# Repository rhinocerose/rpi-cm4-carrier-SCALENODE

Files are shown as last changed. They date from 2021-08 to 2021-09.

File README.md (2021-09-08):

# Scalenode platform

Copyright (c) 2020-2021 [Antmicro](https://www.antmicro.com>)

[Home Page](https://opensource.antmicro.com/projects/scalenode)



## Overview

This repository contains the PCB design files for a baseboard supporting Raspberry Pi Compute Module 4.
The baseboard has been optimized for 19-inch rack mount installations for distributed multi-node computing systems.

## Key features

* Supports Raspberry Pi CM4
* Gigabit Ethernet with integrated PoE circuitry
* On-board M.2 (key-M) slot supporting NVMe SSDs 
* Slim PCB outline for 1U chassis
* Expansion connector for peripherals connected over USB
* Expansion connector for HDMI adapters

## Board layout and dimensions



## Design status

The PCB design files were prepared in KiCad.
Prototypes of revision 1.0.0 are now being verified.

## License

[Apache-2.0](LICENSE)

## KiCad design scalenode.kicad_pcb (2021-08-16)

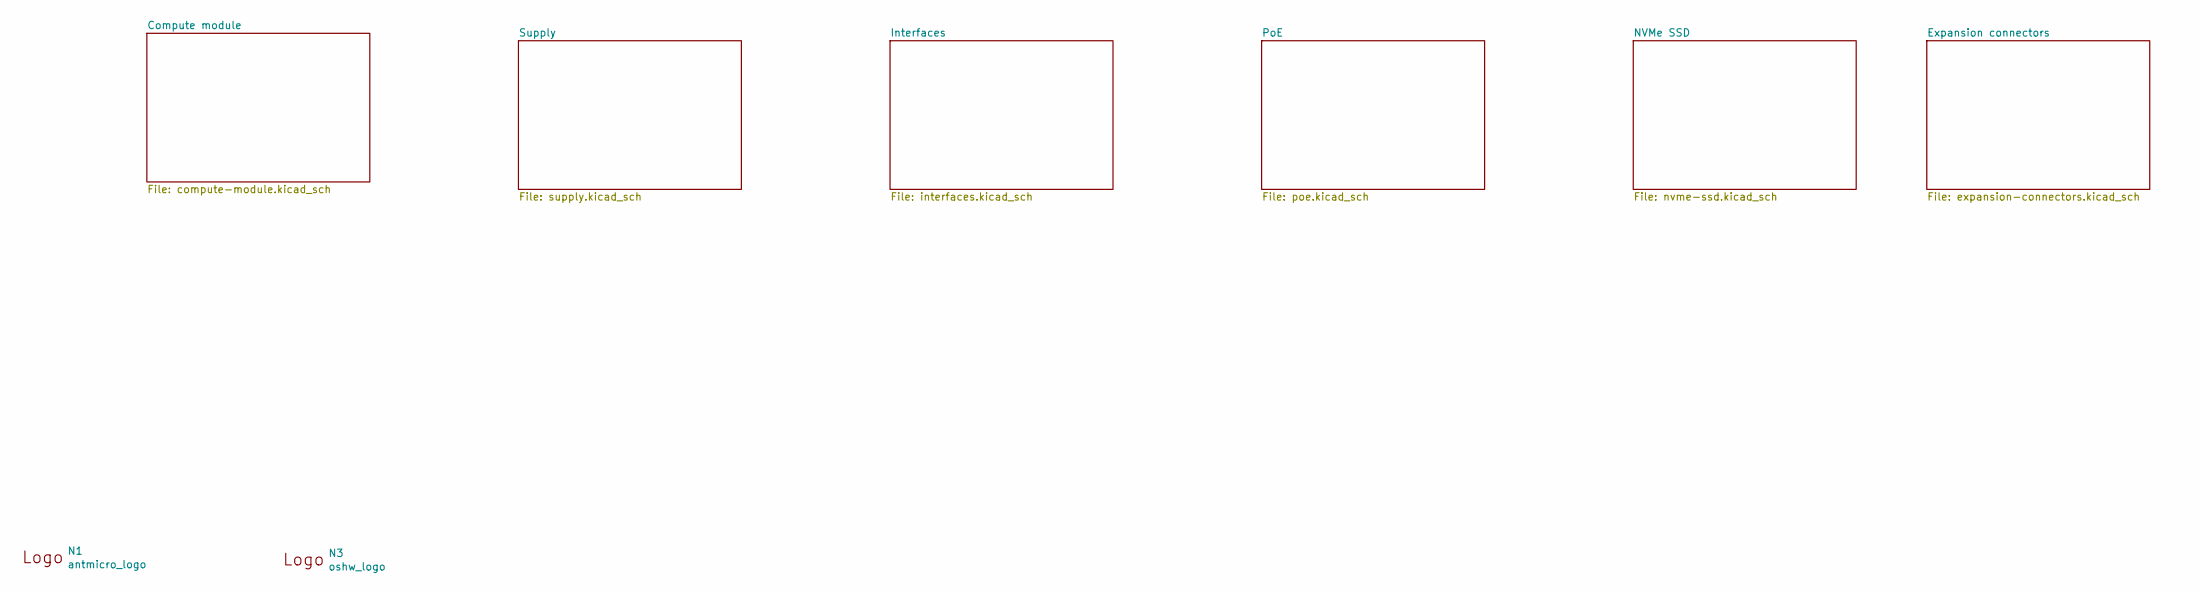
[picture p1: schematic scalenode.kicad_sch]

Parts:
N1: antmicro_logo; antmicro-logo_scaled_15mm
N3: oshw_logo; oshw-logo

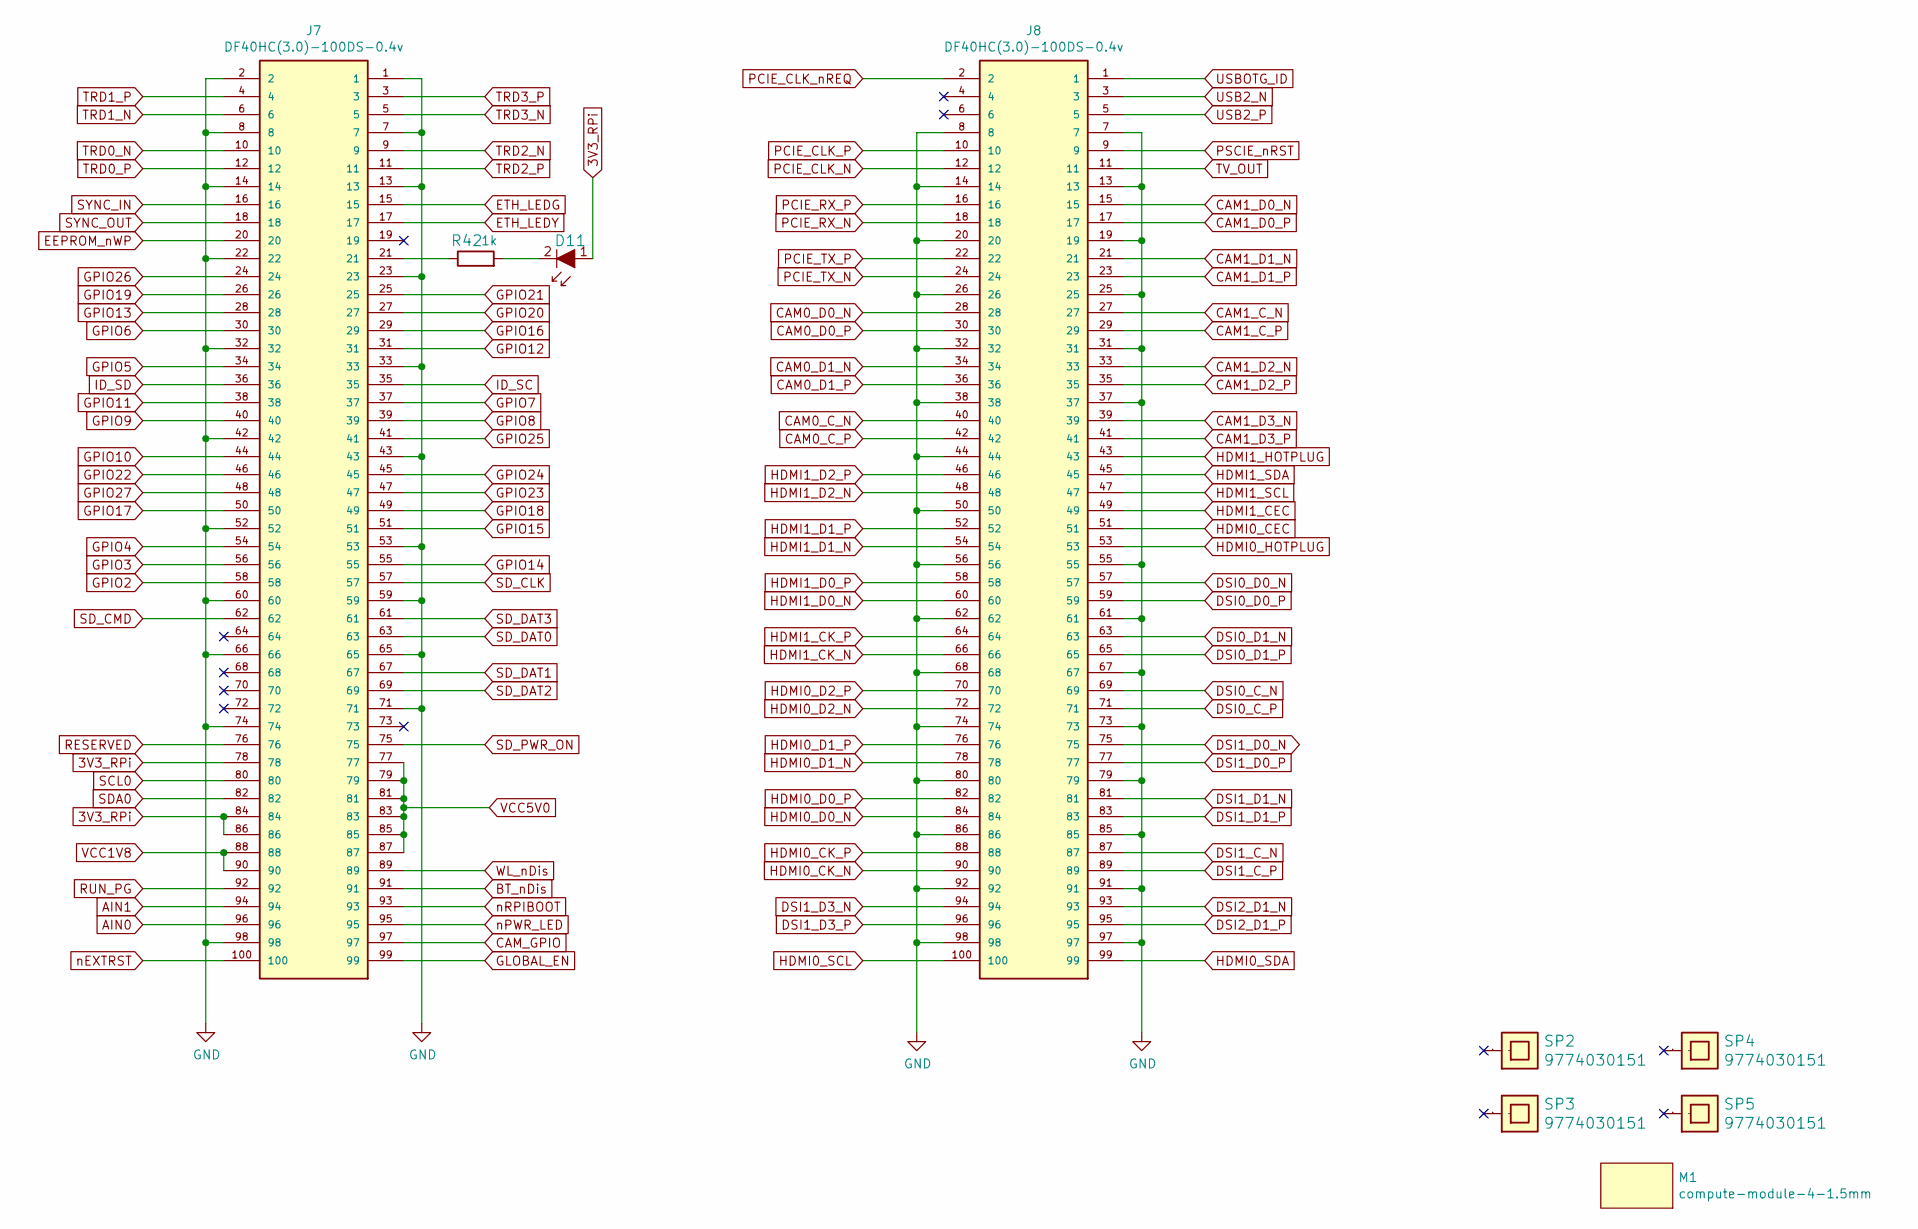
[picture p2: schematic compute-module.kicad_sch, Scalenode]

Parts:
D11: KP-1608CGCK; LED_0603; MPN KP-1608CGCK
J7, J8: DF40HC(3.0)-100DS-0.4v; DF40HC-3.0-100DS-0.4v
M1: compute-module-4-1.5mm
R42: R_1k_0603; 0603-res; MPN CR0603-JW-102ELF
SP2, SP3, SP4, SP5: 9774030151; MPN 9774030151

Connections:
AIN0: J7.96
AIN1: J7.94
BT_nDis: J7.91
CAM0_C_N: J8.40
CAM0_C_P: J8.42
CAM0_D0_N: J8.28
CAM0_D0_P: J8.30
CAM0_D1_N: J8.34
CAM0_D1_P: J8.36
CAM1_C_N: J8.27
CAM1_C_P: J8.29
CAM1_D0_N: J8.15
CAM1_D0_P: J8.17
CAM1_D1_N: J8.21
CAM1_D1_P: J8.23
CAM1_D2_N: J8.33
CAM1_D2_P: J8.35
CAM1_D3_N: J8.39
CAM1_D3_P: J8.41
CAM_GPIO: J7.97
DSI0_C_N: J8.69
DSI0_C_P: J8.71
DSI0_D0_N: J8.57
DSI0_D0_P: J8.59
DSI0_D1_N: J8.63
DSI0_D1_P: J8.65
DSI1_C_N: J8.87
DSI1_C_P: J8.89
DSI1_D0_N: J8.75
DSI1_D0_P: J8.77
DSI1_D1_N: J8.81
DSI1_D1_P: J8.83
DSI1_D3_N: J8.94
DSI1_D3_P: J8.96
DSI2_D1_N: J8.93
DSI2_D1_P: J8.95
EEPROM_nWP: J7.20
ETH_LEDG: J7.15; also elsewhere on the board
ETH_LEDY: J7.17; also elsewhere on the board
GLOBAL_EN: J7.99
GND: J7.1, J7.2, J7.7, J7.8, J7.13, J7.14, J7.22, J7.23, J7.32, J7.33, J7.42, J7.43, J7.52, J7.53, J7.59, J7.60, J7.65, J7.66, J7.71, J7.74, J7.98, J8.7, J8.8, J8.13, J8.14, J8.19, J8.20, J8.25, J8.26, J8.31, J8.32, J8.37, J8.38, J8.44, J8.50, J8.55, J8.56, J8.61, J8.62, J8.67, J8.68, J8.73, J8.74, J8.79, J8.80, J8.85, J8.86, J8.91, J8.92, J8.97, J8.98; also elsewhere on the board
GPIO2: J7.58
GPIO3: J7.56; also elsewhere on the board
GPIO4: J7.54
GPIO5: J7.34
GPIO6: J7.30
GPIO7: J7.37
GPIO8: J7.39
GPIO9: J7.40
GPIO10: J7.44
GPIO11: J7.38
GPIO12: J7.31
GPIO13: J7.28
GPIO14: J7.55
GPIO15: J7.51
GPIO16: J7.29
GPIO17: J7.50
GPIO18: J7.49
GPIO19: J7.26
GPIO20: J7.27
GPIO21: J7.25
GPIO22: J7.46
GPIO23: J7.47
GPIO24: J7.45
GPIO25: J7.41
GPIO26: J7.24
GPIO27: J7.48
HDMI0_CEC: J8.51
HDMI0_CK_N: J8.90
HDMI0_CK_P: J8.88
HDMI0_D0_N: J8.84
HDMI0_D0_P: J8.82
HDMI0_D1_N: J8.78
HDMI0_D1_P: J8.76
HDMI0_D2_N: J8.72
HDMI0_D2_P: J8.70
HDMI0_HOTPLUG: J8.53
HDMI0_SCL: J8.100
HDMI0_SDA: J8.99
HDMI1_CEC: J8.49
HDMI1_CK_N: J8.66
HDMI1_CK_P: J8.64
HDMI1_D0_N: J8.60
HDMI1_D0_P: J8.58
HDMI1_D1_N: J8.54
HDMI1_D1_P: J8.52
HDMI1_D2_N: J8.48
HDMI1_D2_P: J8.46
HDMI1_HOTPLUG: J8.43
HDMI1_SCL: J8.47
HDMI1_SDA: J8.45
ID_SC: J7.35
ID_SD: J7.36
unnamed: D11.2, R42.2
unnamed: J7.21, R42.1
PCIE_CLK_N: J8.12; also elsewhere on the board
PCIE_CLK_P: J8.10; also elsewhere on the board
PCIE_CLK_nREQ: J8.2; also elsewhere on the board
PCIE_RX_N: J8.18; also elsewhere on the board
PCIE_RX_P: J8.16; also elsewhere on the board
PCIE_TX_N: J8.24; also elsewhere on the board
PCIE_TX_P: J8.22; also elsewhere on the board
PSCIE_nRST: J8.9; also elsewhere on the board
RESERVED: J7.76
RUN_PG: J7.92
SCL0: J7.80
SDA0: J7.82
SD_CLK: J7.57; also elsewhere on the board
SD_CMD: J7.62; also elsewhere on the board
SD_DAT0: J7.63; also elsewhere on the board
SD_DAT1: J7.67; also elsewhere on the board
SD_DAT2: J7.69; also elsewhere on the board
SD_DAT3: J7.61; also elsewhere on the board
SD_PWR_ON: J7.75
SYNC_IN: J7.16
SYNC_OUT: J7.18
TRD0_N: J7.10; also elsewhere on the board
TRD0_P: J7.12; also elsewhere on the board
TRD1_N: J7.6; also elsewhere on the board
TRD1_P: J7.4; also elsewhere on the board
TRD2_N: J7.9; also elsewhere on the board
TRD2_P: J7.11; also elsewhere on the board
TRD3_N: J7.5; also elsewhere on the board
TRD3_P: J7.3; also elsewhere on the board
TV_OUT: J8.11
USB2_N: J8.3; also elsewhere on the board
USB2_P: J8.5; also elsewhere on the board
USBOTG_ID: J8.1; also elsewhere on the board
VCC1V8: J7.88, J7.90
VCC5V0: J7.77, J7.79, J7.81, J7.83, J7.85, J7.87; also elsewhere on the board
WL_nDis: J7.89
nEXTRST: J7.100
nPWR_LED: J7.95
nRPIBOOT: J7.93

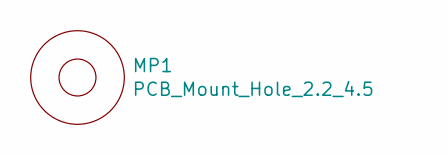
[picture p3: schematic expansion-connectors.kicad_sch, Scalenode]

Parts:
MP1: PCB_Mount_Hole_2.2_4.5; mounting-hole-2.2mm

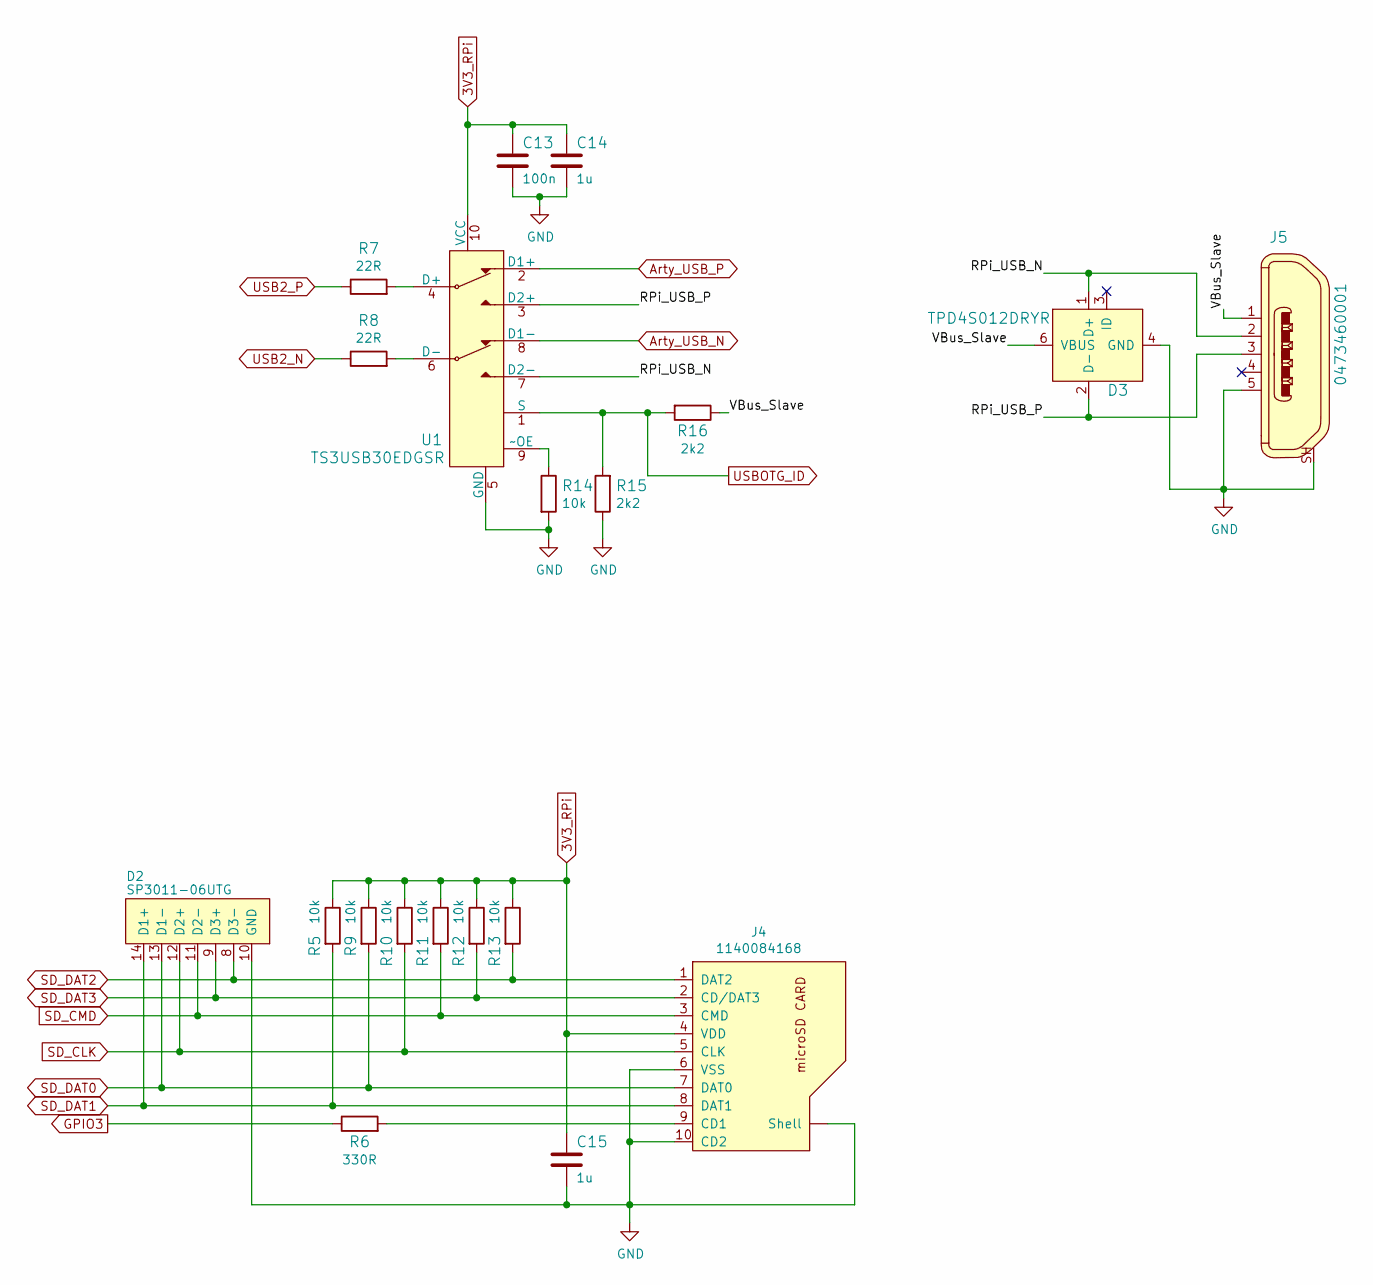
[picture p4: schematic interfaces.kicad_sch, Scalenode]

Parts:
C13: C_100n_0402; 0402-cap; MPN 0402X104K6R3CT
C14, C15: C_1u_0402; 0402-cap; MPN C1005X6S1A105K050BC
D2: SP3011-06UTG; SON50P350X135X55-14N; MPN SP3011-06UTG
D3: TPD4S012DRYR; UFDFN-6_1.45x1mm; MPN TPD4S012DRYR
J4: 1140084168; MicroSD_1140084168; MPN 1140084168
J5: 0473460001; USB_Micro_B_Female_0473460001; MPN 0473460001
R5, R9, R10, R11, R12, R13, R14: R_10k_0402; 0402-res; MPN CRCW040210K0FKEDHP
R6: R_330R_0402; 0402-res; MPN MCMR04X3300FTL
R7, R8: R_22R_0402; 0402-res; MPN CRCW040222R0FKED
R15, R16: R_2k2_0402; 0402-res; MPN RC0402FR-072K2L
U1: TS3USB30EDGSR; MSOP-10_W3mm; MPN TS3USB30EDGSR

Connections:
/Interfaces/RPi_USB_N: D3.1 (D+), J5.2, U1.7 (D2-)
/Interfaces/RPi_USB_P: D3.2 (D-), J5.3, U1.3 (D2+)
Arty_USB_N: U1.8 (D1-)
Arty_USB_P: U1.2 (D1+)
GND: C13.2, C14.2, C15.2, D2.10 (GND), D3.4 (GND), J4.6 (VSS), J4.10 (CD2), J4.~ (Shell), J5.5, J5.SH, R14.2, R15.1, U1.5 (GND); also elsewhere on the board
GPIO3: R6.1; also elsewhere on the board
unnamed: J4.9 (CD1), R6.2
unnamed: R7.2, U1.4 (D+)
unnamed: R8.2, U1.6 (D-)
unnamed: R14.1, U1.9 (~OE)
SD_CLK: D2.12 (D2+), J4.5 (CLK), R10.2; also elsewhere on the board
SD_CMD: D2.11 (D2-), J4.3 (CMD), R11.2; also elsewhere on the board
SD_DAT0: D2.13 (D1-), J4.7 (DAT0), R9.2; also elsewhere on the board
SD_DAT1: D2.14 (D1+), J4.8 (DAT1), R5.2; also elsewhere on the board
SD_DAT2: D2.8 (D3-), J4.1 (DAT2), R13.2; also elsewhere on the board
SD_DAT3: D2.9 (D3+), J4.2 (CD/DAT3), R12.2; also elsewhere on the board
USB2_N: R8.1; also elsewhere on the board
USB2_P: R7.1; also elsewhere on the board
USBOTG_ID: R15.2, R16.2, U1.1 (S); also elsewhere on the board

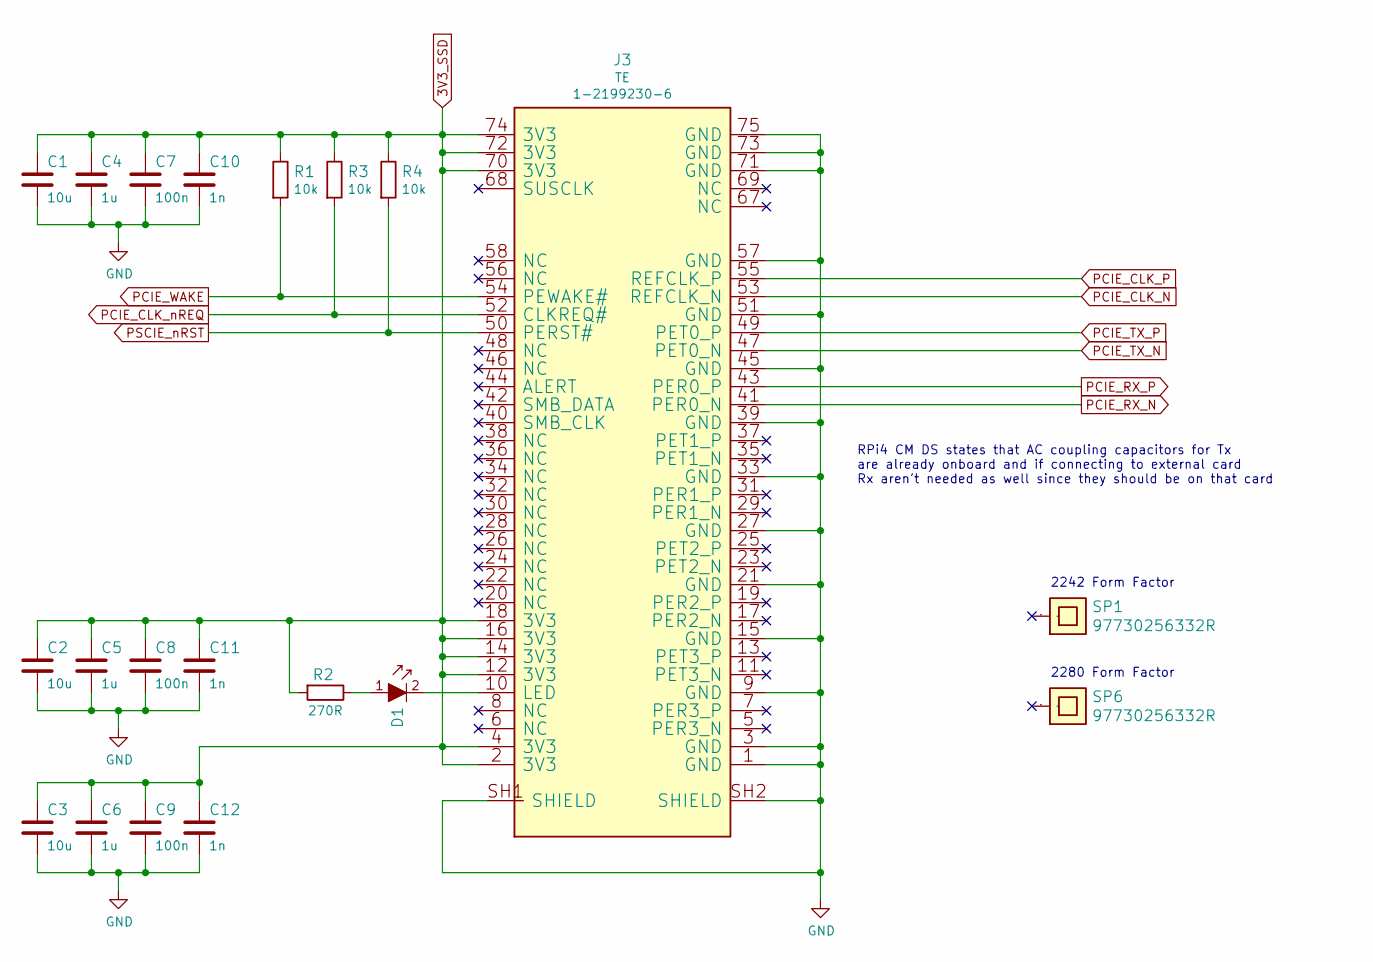
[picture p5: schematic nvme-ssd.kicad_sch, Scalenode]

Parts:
C1, C2, C3: C_10u_0603; 0603-cap; MPN GRM188R61A106KE69D
C4, C5, C6: C_1u_0603; 0603-cap; MPN 0603YD105KAT2A
C7, C8, C9: C_100n_0603; 0603-cap; MPN 0603YC104KAZ2A
C10, C11, C12: C_1n_0603; 0603-cap; MPN 06031C102JAT2A
D1: KP-1608CGCK; LED_0603; MPN KP-1608CGCK
J3: 1-2199230-6; MPN 1-2199230-6
R1, R3, R4: R_10k_0603; 0603-res; MPN CR0603-JW-103ELF
R2: R_270R_0603; 0603-res; MPN CRGH0603F270R
SP1, SP6: 97730256332R; MPN 97730256332R

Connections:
3V3_SSD: C1.1, C2.1, C3.1, C4.1, C5.1, C6.1, C7.1, C8.1, C9.1, C10.1, C11.1, C12.1, J3.2 (3V3), J3.4 (3V3), J3.12 (3V3), J3.14 (3V3), J3.16 (3V3), J3.18 (3V3), J3.70 (3V3), J3.72 (3V3), J3.74 (3V3), R1.1, R2.2, R3.1, R4.1; also elsewhere on the board
GND: C1.2, C2.2, C3.2, C4.2, C5.2, C6.2, C7.2, C8.2, C9.2, C10.2, C11.2, C12.2, J3.1 (GND), J3.3 (GND), J3.9 (GND), J3.15 (GND), J3.21 (GND), J3.27 (GND), J3.33 (GND), J3.39 (GND), J3.45 (GND), J3.51 (GND), J3.57 (GND), J3.71 (GND), J3.73 (GND), J3.75 (GND), J3.SH1 (SHIELD), J3.SH2 (SHIELD); also elsewhere on the board
unnamed: D1.1, R2.1
unnamed: D1.2, J3.10 (LED)
PCIE_CLK_N: J3.53 (REFCLK_N); also elsewhere on the board
PCIE_CLK_P: J3.55 (REFCLK_P); also elsewhere on the board
PCIE_CLK_nREQ: J3.52 (CLKREQ#), R3.2; also elsewhere on the board
PCIE_RX_N: J3.41 (PER0_N); also elsewhere on the board
PCIE_RX_P: J3.43 (PER0_P); also elsewhere on the board
PCIE_TX_N: J3.47 (PET0_N); also elsewhere on the board
PCIE_TX_P: J3.49 (PET0_P); also elsewhere on the board
PCIE_WAKE: J3.54 (PEWAKE#), R1.2
PSCIE_nRST: J3.50 (PERST#), R4.2; also elsewhere on the board

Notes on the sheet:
RPi4 CM DS states that AC coupling capacitors for Tx are already onboard and if connecting to external card Rx aren't needed as well since they should be on that card
2242 Form Factor
2280 Form Factor

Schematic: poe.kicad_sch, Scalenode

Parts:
C20, C21, C23, C24: C_10n_0402; 0402-cap; MPN 04025G103ZAT2A
C22, C25, C50: C_1n_1210_2kV; 1210-cap; MPN C1210C102KGRACTU
C26: C_10n_0603; 0603-cap; MPN 06031C103JAT2A
C27: C_270p_0603; 0603-cap; MPN MC0603B271K500CT
C28: C_100n_0805_100V; 0805-cap; MPN CL21B104KCFNNNE
C29: C_47u_ELEC_100V; CP_Elec_10x10.5; MPN EEEHA2A470UP
C30: C_100n_0603; 0603-cap; MPN 0603YC104KAZ2A
C31: C_220n_0603_25V; 0603-cap; MPN C1608X5R1H474K080AB
C32, C34, C36: C_1u_1210_100V; 1210-cap; MPN 12101C105K4Z2A
C33: C_22u_ELEC_25V; CP_Elec_5x5.8; MPN EEEFK1E220R
C35, C43, C47: C_1u_0603; 0603-cap; MPN 0603YD105KAT2A
C37, C40: C_470n_0603; 0603-cap; MPN C1608X5R1H474K080AB
C38: C_100p_0402; 0402-cap; MPN 0402N101J500CT
C39: C_82n_0603; 0603-cap; MPN MC0603B823K500CT
C41, C42, C44: C_47u_0603; 0603-cap; MPN GRM188R60J476ME15D
C45, C46: C_220u_KEMET_B; KEMET_B; MPN TMCMB0J227MTRF
C48: C_1n_0603; 0603-cap; MPN 06031C102JAT2A
C49: C_1n2_0603; 0603-res; MPN C0603C122K5RACTU
D4, D5: MB10S; MPN MB10S
D6: SMAJ58A-13-F; DO-214AC; MPN SMAJ58A-13-F
D7, D9: BAS16E6327HTSA1; SOT-23-3; MPN BAS16E6327HTSA1
D8: KP-1608CGCK; LED_0603; MPN KP-1608CGCK
D10: MURA120T3G; DO-214AC; MPN MURA120T3G
D12: TLV431ACDBVR; SOT-23-5; MPN TLV431ACDBVR
D13, D14: BAV99W,115; SOT-323; MPN BAV99W,115
FB1, FB2: BLM21PG221SN1D; 0805-res; MPN BLM21PG221SN1D
IC2: TPS2378DDA; SOIC127P600X170-9N; MPN TPS2378DDA; Mouser Part Number 595-TPS2378DDA
J6: SS-74800-144; MPN SS-74800-144
L3: H6096NL; SOIC127P1594X685-24N; MPN H6096NL
L4: DO1608C-332MLB; L_6.3x4.5; MPN DO1608C-332MLB
L5: DR74-R33-R; L_DR74; MPN DR74-R33-R
Q1, Q2, Q5: MMBT3906,215; SOT-23-3; MPN MMBT3906,215
Q3: SI7848BDP-T1-E3; PowerPAK_SO-8_Single; MPN SI7848BDP-T1-E3
Q4: SI7450DP-T1-GE3; PowerPAK_SO-8_Single; MPN SI7450DP-T1-GE3
R17: R_0R_1206; 1206-res; MPN MCMR12X000_PTL
R21, R22: R_220R_0402; 0402-res; MPN ERJ2GEJ221X
R23, R24, R25, R26, R27, R28, R29, R30: R_75R_0402; 0402-res; MPN RC0402FR-0775RL
R31: R_10k7_0603; 0603-res; MPN CRCW060310K7FKEA
R32, R35, R47, R49: R_10k_0603; 0603-res; MPN CR0603-JW-103ELF
R33: R_4k64_0603; 0603-res; MPN CRCW06034K64FKEA
R34: R_63R4_0402; 0402-res; MPN CRCW040263R4FKED
R36: R_24k9_0402; 0402-res; MPN WR04X2492FTL
R37: R_30k1_0603; 0603-res; MPN CRCW060330K1FKEA
R38: R_4k99_0402; 0402-res; MPN MCMR04X4991FTL
R39: R_24R9_0603; 0603-res; MPN CRCW060324R9FKEA
R40: R_15k_0603; 0603-res; MPN CR0603-FX-1502ELF
R41: R_20R_0603; 0603-res; MPN CRCW060320R0FKEA
R43: R_R33_2512; 2512; MPN RLP73K3AR33JTE
R44: R_1k_0402; 0402-res; MPN CR0402-FX-1001GLF
R45, R46: R_1k_0603; 0603-res; MPN CR0603-JW-102ELF
R48, R53: R_49R9_0603; 0603-res; MPN CRCW060349R9FKEA
R50: R_10R_2010; 2010-res; MPN WF20P10R0FTL
R51, R54: R_41k2_0603; 0603-res; MPN CRCW060341K2FKEA
R52: R_13k3_0603; 0603-res; MPN CRCW060313K3FKEA
T1: P0926NL; Pulse_P0926NL; MPN P0926
T2: POE300F-50L; POE300F-24LD; MPN POE300F-50L
TP3, TP4, TP5, TP6: TP_SMD1MM; Testpoint_smd_1mm
U3: UCC3809D2; SOIC-8_W3.9mm; MPN UCC3809D2
U4: TCMT1107; MPN TCMT1107

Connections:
/PoE/CDB: C26.1, IC2.6 (CDB), U3.2 (SS)
/PoE/CTRL_FB: C38.1, R35.1, R44.2, R45.1, U3.1 (FB)
/PoE/CTRL_OUT: C37.2, R39.1, U3.6 (OUT)
/PoE/CTRL_REF: C35.1, R38.1, U3.8 (REF), U4.4
/PoE/CTRL_VDD: C31.1, C33.1, D7.3, D8.1, R37.2, TP3.1, U3.7 (VDD)
/PoE/PAIR12: C20.1, D4.3, L3.24 (MCT1)
/PoE/PAIR36: C21.1, D4.4, L3.21 (MCT2)
/PoE/PAIR45: C23.1, D5.3, L3.18 (MCT3)
/PoE/PAIR78: C24.1, D5.4, L3.15 (MCT4)
/PoE/T_ETH_D0_N: J6.2, L3.22 (MX1-)
/PoE/T_ETH_D0_P: J6.1, L3.23 (MX1+)
/PoE/T_ETH_D1_N: J6.6, L3.19 (MX2-)
/PoE/T_ETH_D1_P: J6.3, L3.20 (MX2+)
/PoE/T_ETH_D2_N: J6.5, L3.16 (MX3-)
/PoE/T_ETH_D2_P: J6.4, L3.17 (MX3+)
/PoE/T_ETH_D3_N: J6.8, L3.13 (MX4-)
/PoE/T_ETH_D3_P: J6.7, L3.14 (MX4+)
ETH_LEDG: J6.11; also elsewhere on the board
ETH_LEDY: J6.9; also elsewhere on the board
GND: C25.1, C41.2, C42.2, C43.2, C44.2, C45.2, C46.2, C47.2, C48.1, C50.1, D12.5 (A), D14.1, Q3.1 (S), Q3.2 (S), Q3.3 (S), Q5.3, R17.2, R47.2, R52.2, T1.2, T1.3, TP5.1; also elsewhere on the board
GNDD: C26.2, C27.2, C29.2, C31.2, C32.2, C33.2, C34.2, C35.2, C38.2, C39.2, IC2.5 (RTN), IC2.8 (APD), Q1.3, Q2.3, R43.2, T1.6, T2.5, U3.5 (GND)
unnamed: C20.2, R23.1
unnamed: C21.2, R24.1
unnamed: C22.1, R23.2, R24.2, R25.2, R26.2
unnamed: C23.2, R25.1
unnamed: C24.2, R26.1
unnamed: C25.2, R27.1, R28.1, R29.1, R30.1
unnamed: C27.1, Q1.1, R31.2, R33.2
unnamed: C30.1, Q1.2, R38.2
unnamed: C30.2, R35.2
unnamed: C32.1, C34.1, C36.1, L4.2, R37.1, R40.1, T2.1, T2.2
unnamed: C36.2, D10.K, R40.2
unnamed: C37.1, T1.1
unnamed: C39.1, R45.2, U4.3
unnamed: C40.1, R47.1, R48.2
unnamed: C40.2, T1.4, T1.5
unnamed: C41.1, C42.1, C44.1, C45.1, L5.1, T2.7, T2.8, T2.9
unnamed: C43.1, D13.3, R49.2
unnamed: C48.2, R50.2
unnamed: C49.1, D12.4 (REF), R52.1, R54.2
unnamed: C49.2, R51.2
unnamed: D4.1, D5.1, FB2.1
unnamed: D4.2, D5.2, FB1.1
unnamed: D7.1, R41.1
unnamed: D8.2, R32.1
unnamed: D9.1, Q2.1, R39.2
unnamed: D9.3, Q2.2, Q4.4 (G)
unnamed: D10.A, Q4.5 (D), T2.3, T2.4
unnamed: D12.3 (K), D13.1, R51.1, U4.2
unnamed: D14.2, Q3.4 (G), Q5.2
unnamed: D14.3, Q5.1, R48.1
unnamed: IC2.2 (DEN), R36.2
unnamed: IC2.3 (CLS), R34.1
unnamed: IC2.7 (T2P), R32.2
unnamed: J6.10, R21.1
unnamed: J6.12, R22.1
unnamed: L3.1 (TCT1), R27.2
unnamed: L3.4 (TCT2), R28.2
unnamed: L3.7 (TCT3), R29.2
unnamed: L3.10 (TCT4), R30.2
unnamed: Q3.5 (D), R50.1, T2.10, T2.11, T2.12
unnamed: Q4.1 (S), Q4.2 (S), Q4.3 (S), R43.1, R44.1
unnamed: R31.1, U3.3 (RT1)
unnamed: R33.1, U3.4 (RT2)
unnamed: R41.2, T2.6
unnamed: R46.2, U4.1
unnamed: R53.2, R54.1, TP6.1
TRD0_N: L3.3 (TD1-); also elsewhere on the board
TRD0_P: L3.2 (TD1+); also elsewhere on the board
TRD1_N: L3.6 (TD2-); also elsewhere on the board
TRD1_P: L3.5 (TD2+); also elsewhere on the board
TRD2_N: L3.9 (TD3-); also elsewhere on the board
TRD2_P: L3.8 (TD3+); also elsewhere on the board
TRD3_N: L3.12 (TD4-); also elsewhere on the board
TRD3_P: L3.11 (TD4+); also elsewhere on the board
VCC5V0: C46.1, C47.1, D13.2, L5.2, R46.1, R49.1, R53.1, TP4.1; also elsewhere on the board
VDD: C28.1, C29.1, D6.K, FB2.2, IC2.1 (VDD), L4.1, R36.1
VSS: C28.2, D6.A, FB1.2, IC2.4 (VSS), IC2.9 (EP), R34.2

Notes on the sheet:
DNP

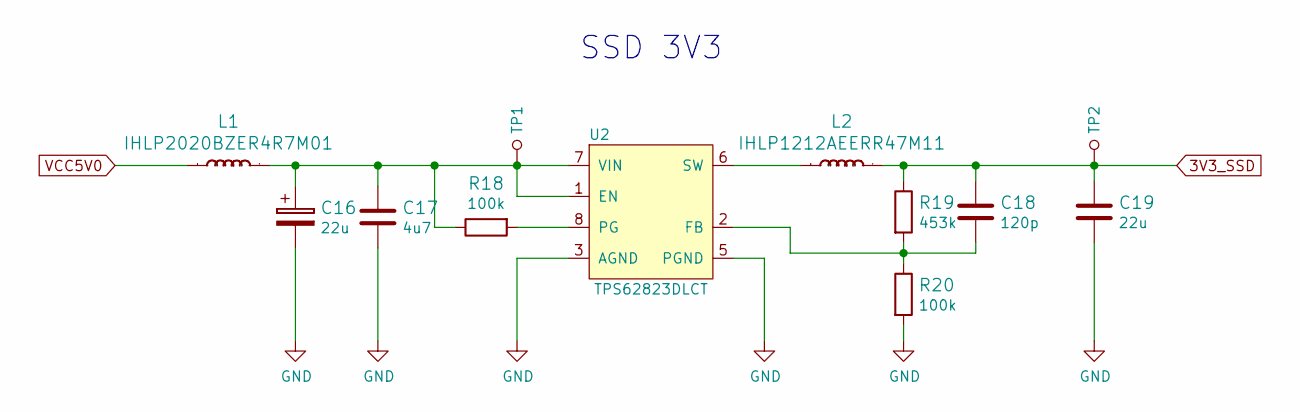
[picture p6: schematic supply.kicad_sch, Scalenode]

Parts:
C16: C_22u_KEMET_A; KEMET_A; MPN T491A226K006AT
C17: C_4u7_0603; 0603-cap; MPN C1608X5R1V475M080AC
C18: C_120p_0402; 0402-res; MPN C0402C121J5GACTU
C19: C_22u_1210; 1210-cap; MPN 1210YD226MAT2A
L1: IHLP2020BZER4R7M01; MPN IHLP1212AEERR47M11
L2: IHLP1212AEERR47M11; IHLP-1212AE; MPN IHLP1212AEERR47M11
R18: R_100k_0603; 0603-res; MPN CR0603-FX-1003HLF
R19: R_453k_0402; 0402-res; MPN CRCW0402453KFKED
R20: R_100k_0402; 0402-res; MPN CRCW0402100KFKEDHP
TP1, TP2: TP_SMD1MM; Testpoint_smd_1mm
U2: TPS62823DLCT; QFN-8_2x1mm; MPN TPS62823DLCT

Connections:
3V3_SSD: C18.1, C19.1, L2.2, R19.1, TP2.1; also elsewhere on the board
GND: C16.2, C17.2, C19.2, R20.2, U2.3 (AGND), U2.5 (PGND); also elsewhere on the board
unnamed: C16.1, C17.1, L1.2, R18.1, TP1.1, U2.1 (EN), U2.7 (VIN)
unnamed: C18.2, R19.2, R20.1, U2.2 (FB)
unnamed: L2.1, U2.6 (SW)
unnamed: R18.2, U2.8 (PG)
VCC5V0: L1.1; also elsewhere on the board

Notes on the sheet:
SSD 3V3

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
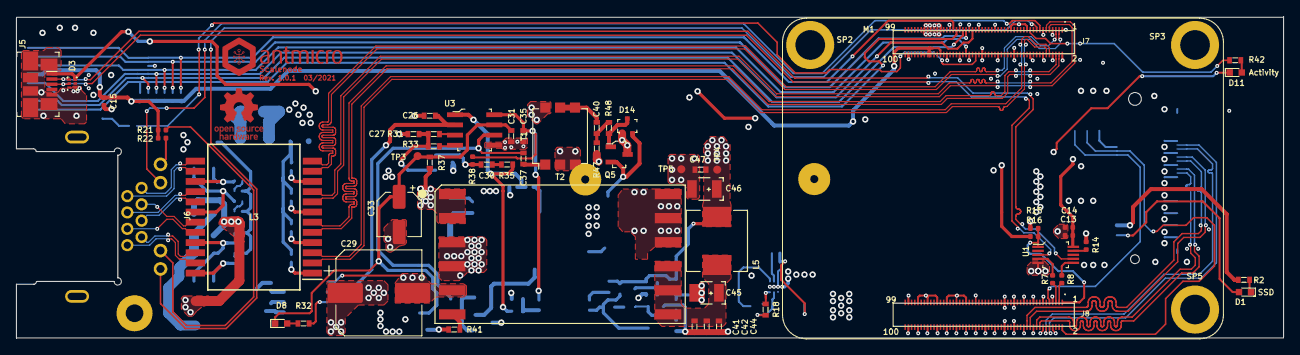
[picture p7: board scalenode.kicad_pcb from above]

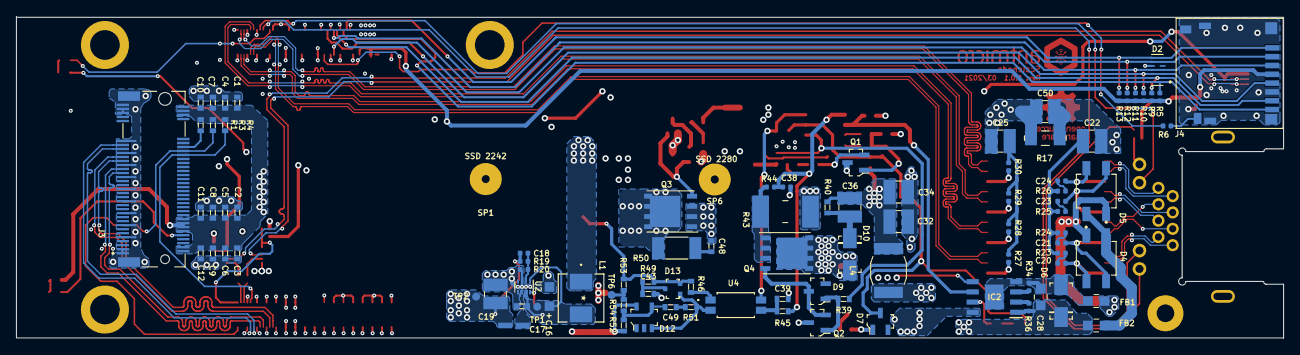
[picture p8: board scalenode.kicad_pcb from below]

Board: 4 copper layers, 158.1 x 40.2 mm, 158 parts (95 on the bottom side), 115 nets.

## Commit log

2021-08-16 Removed USB
    [compute-module.kicad_sch, expansion-connectors.kicad_sch, interfaces.kicad_sch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]
2021-08-16 Moved CM4 board, rerouted power
    [scalenode.kicad_pcb]

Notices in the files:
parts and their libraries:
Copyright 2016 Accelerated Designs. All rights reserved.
